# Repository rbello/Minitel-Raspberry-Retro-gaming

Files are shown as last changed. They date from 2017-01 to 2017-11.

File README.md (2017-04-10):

# Retro gaming video game console + Old French Minitel (DIY)

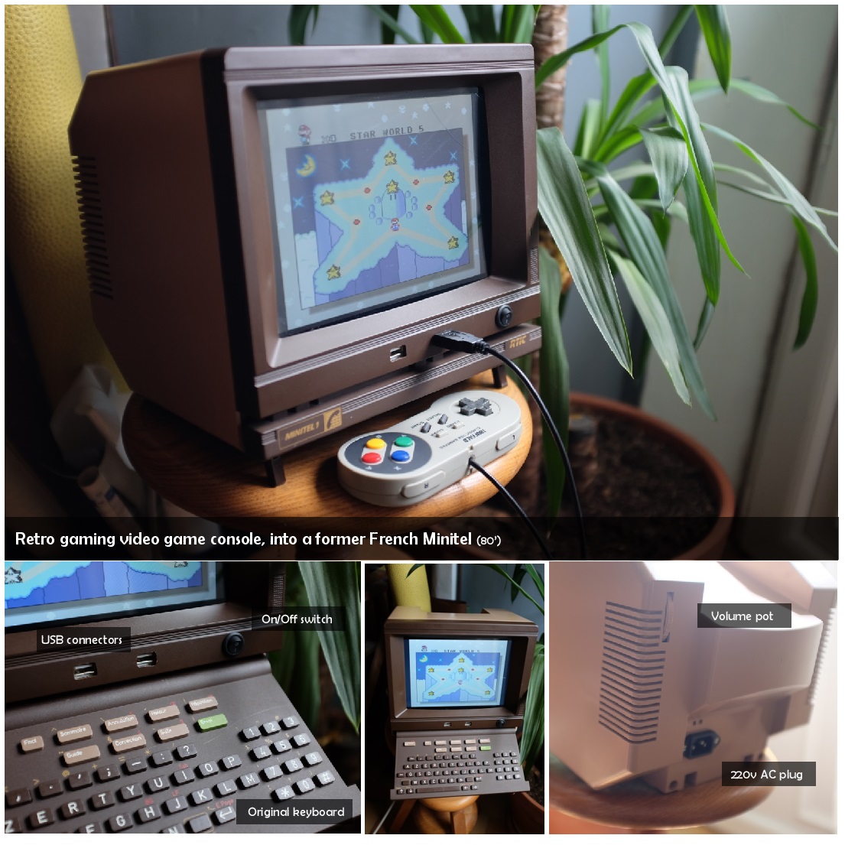
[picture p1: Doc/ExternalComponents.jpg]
External components


### A SuperSwag Project

The Minitel was a Videotex online service accessible through telephone lines, and is considered one of the world's most successful pre-World Wide Web online services. The service was rolled out in France in 1982 by the *Postes, Télégraphes et Téléphones* compagny. From its early days, users could make online purchases, make train reservations, check stock prices, search the telephone directory, have a mail box, and chat in a similar way to that now made possible by the Internet. Then, this service was retired on 30 June 2012.

Minitel used terminals consisting of a text-based screen, keyboard and modem. Simple graphics could be displayed using a set of predefined graphical characters. It used a half-duplex asymmetric data transmission via its modem. It downlinked at 1200 bit/s and uplinked at 75 bit/s. This allowed fast downloads, for the time.

I decided to reuse an old minitel in order to make a retro gaming console, because the case is cute and contains an embedded screen. To make the system work, I used a Raspberry Pi as a computer, an Arduino Nano to control power and peripherals, a 10'' LCD and a stereo speaker. I managed to reuse the original keyboard (with some DIY) but I also added two front USB ports to connect more modern peripherals, such as gamepads.

Here's how it works:

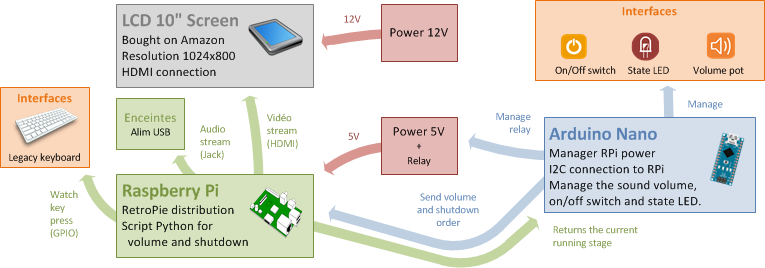
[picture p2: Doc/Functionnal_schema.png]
Functionnal schema


Inside, I had to make a plastic support thanks to a 3D printer to contain all the electronic components. The Arduino Nano manages the life cycle of the system. It communicates with the Raspberry using the I2C connection to send him the sound volume value (which can be changed with the minitel's original pot) and the order of shutdown. The Raspberry contains a special retro gaming linux distribution that ships all the emulators from consoles prior to the PlayStation. The display is ensured by an LCD screen specially bought for the occasion, which I had to cut out to adapt it to the original box.

Here's what it looks like inside the box:

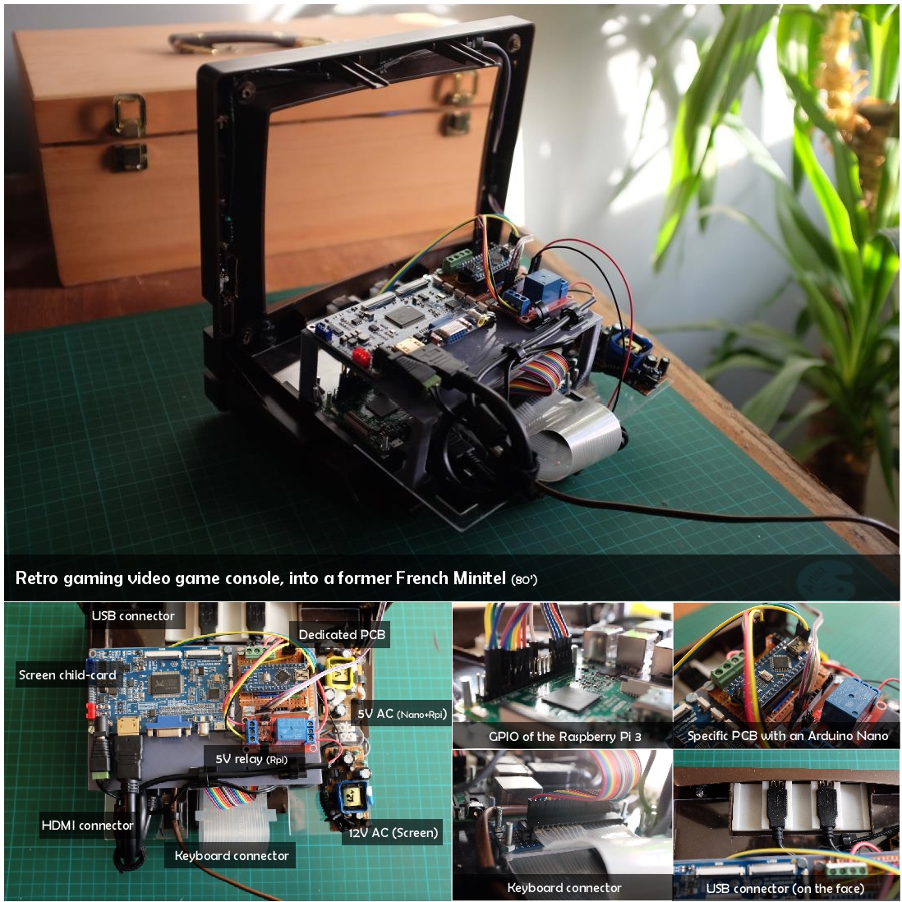
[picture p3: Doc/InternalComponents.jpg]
Internal components


### Conception

#### Power management / Electronic design
Naturally, raspberry is not able to handle an on/off button that allows the power supply to be turned off properly once the embedded linux has shutdown. To do this, I have added an arduino that controls the power supply and manages the system life cycle.

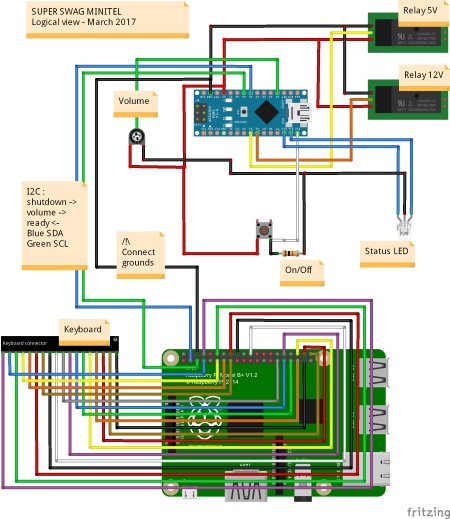
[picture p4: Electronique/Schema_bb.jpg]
Electronic schema


- [Arduino Sketch : INO file](https://github.com/rbello/Minitel-Raspberry-Retro-gaming/blob/master/SuperSwag3615.ino)
- [Python script : I2C connection polling](https://github.com/rbello/Minitel-Raspberry-Retro-gaming/blob/master/Scripts%20Raspberry/polling.py)
- [Bash script : startup process](https://github.com/rbello/Minitel-Raspberry-Retro-gaming/blob/master/Scripts%20Raspberry/startup.sh)

#### Keyboard
The original minitel keyboard is connected directly to the raspberry pi. It works perfectly with the following script:
- [Python script : Keyboard polling](https://github.com/rbello/Minitel-Raspberry-Retro-gaming/blob/master/Scripts%20Raspberry/keyboard.py)

#### 3D printed components
To integrate all the components in the case and offer USB interfaces on the front, I printed several plastic components using a 3D printer. Models are available in the Casing directory.
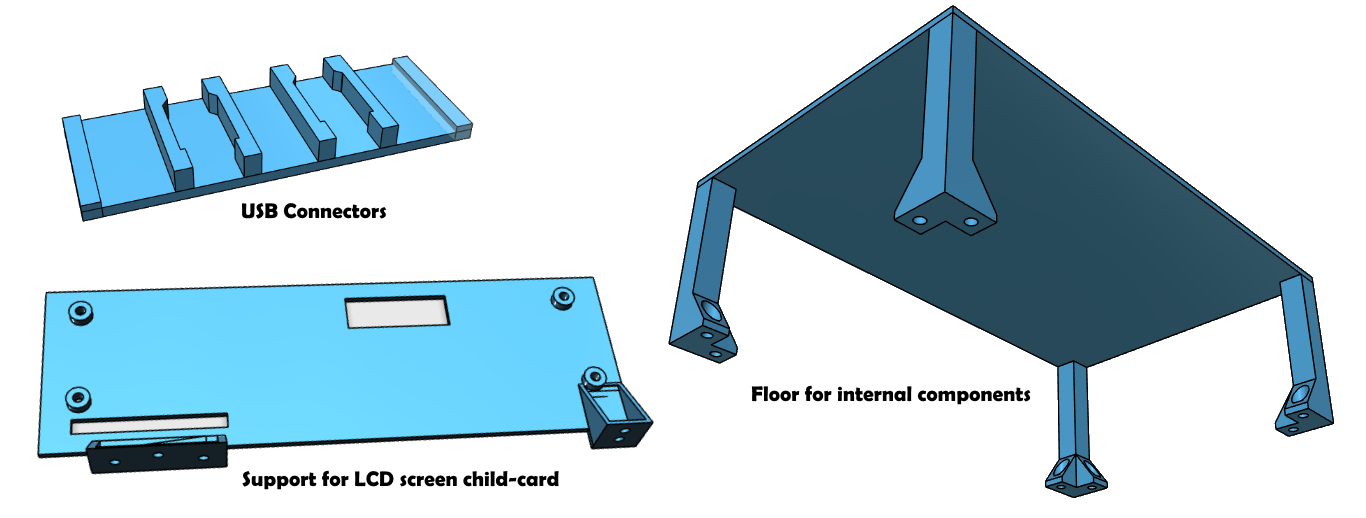
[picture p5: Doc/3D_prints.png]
3D prints


#### Materials

- The Raspberry Pi 3 (Model B) as main engine
- Arduino Nano (from SODIAL)
- [10.1 inch LCD touch screen](https://www.amazon.fr/gp/product/B01E8O5B20/ref=oh_aui_detailpage_o00_s00?ie=UTF8&psc=1)
- A simple USB audio speaker with Jack connector

#### Software

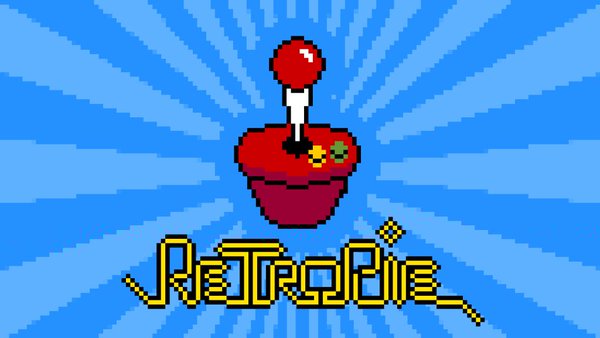
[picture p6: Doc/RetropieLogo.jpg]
RetropieLogo


On the raspberry pi:
- Installed Operating System : [RetroPie](https://retropie.org.uk/)
- Plus some linux packages: i2c-tools and python-smbus, alsa-utils (for sounds), python-uinput (for keyboard)
- I also replaced the [/boot/config.txt](https://github.com/rbello/Minitel-Raspberry-Retro-gaming/blob/master/Scripts%20Raspberry/config.txt) to adapt screen resolution
- See [setup document](https://github.com/rbello/Minitel-Raspberry-Retro-gaming/blob/master/Scripts%20Raspberry/setup.txt) for more details

I also used:
- Scraper : [Universal XML Scraper](https://github.com/Universal-Rom-Tools/Universal-XML-Scraper/releases)

#### Automatic Synch

The console automatically synchronizes game saves backups with an HTTP server. A raspberry-side python script and a server-side PHP script ensure the synchronization of files periodically, thanks to a CRON task.

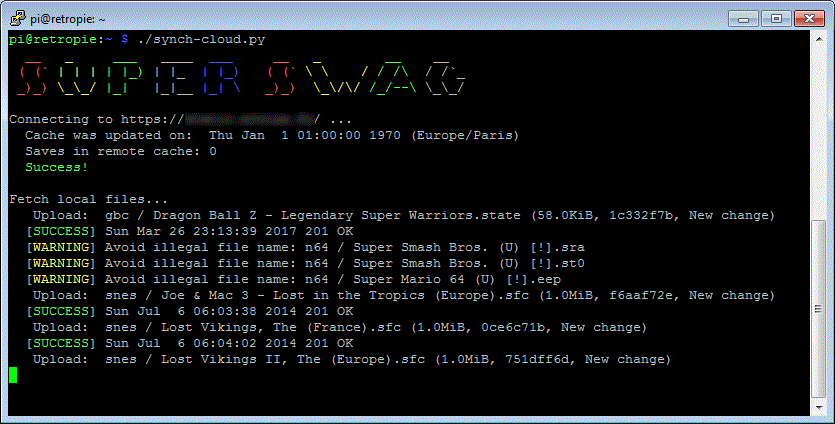
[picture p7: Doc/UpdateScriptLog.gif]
SynchScript


[Python](https://github.com/rbello/Minitel-Raspberry-Retro-gaming/blob/master/Scripts%20Raspberry/synch-cloud.py) and [PHP](https://github.com/rbello/Minitel-Raspberry-Retro-gaming/blob/master/Synchro/index.php) scripts uses an OTP authentication using algorithms specified in RFC 6238 and RFC 4226 (also used by Google Authenticator).

*This repository contains all the files allowing the creation of a similar console. This content is copyright free.*

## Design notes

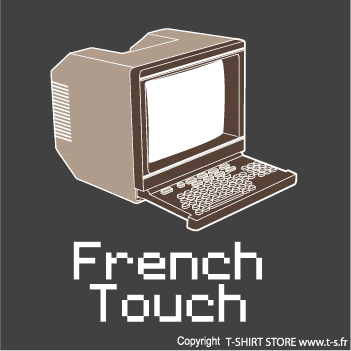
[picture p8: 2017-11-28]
Doc/Recherche1.gif

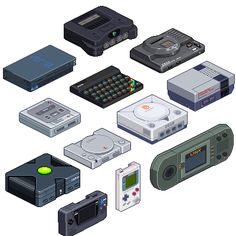
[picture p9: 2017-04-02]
Doc/ConsolesRetro.jpg

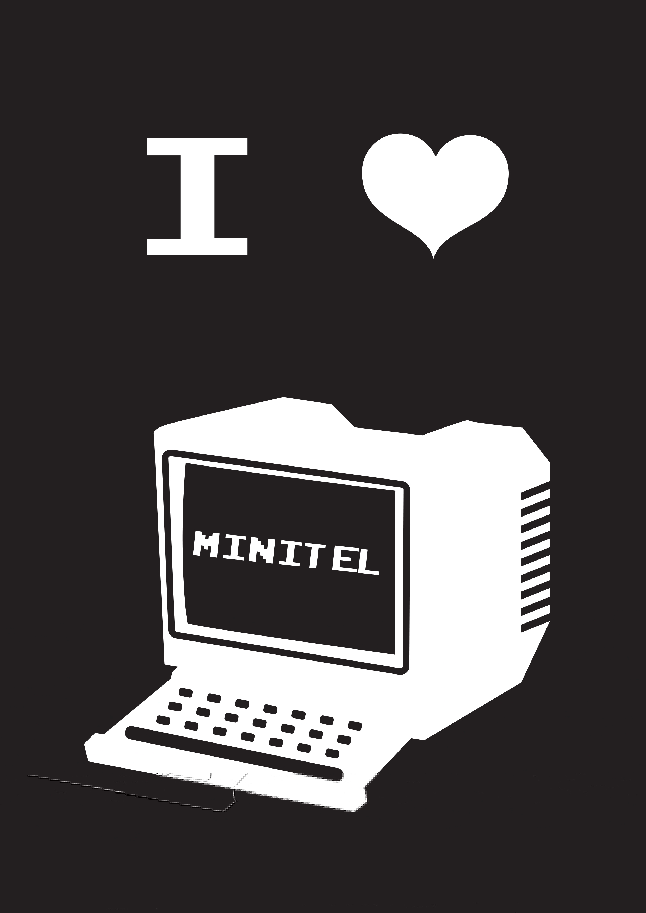
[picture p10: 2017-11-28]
Doc/Recherche2.jpg

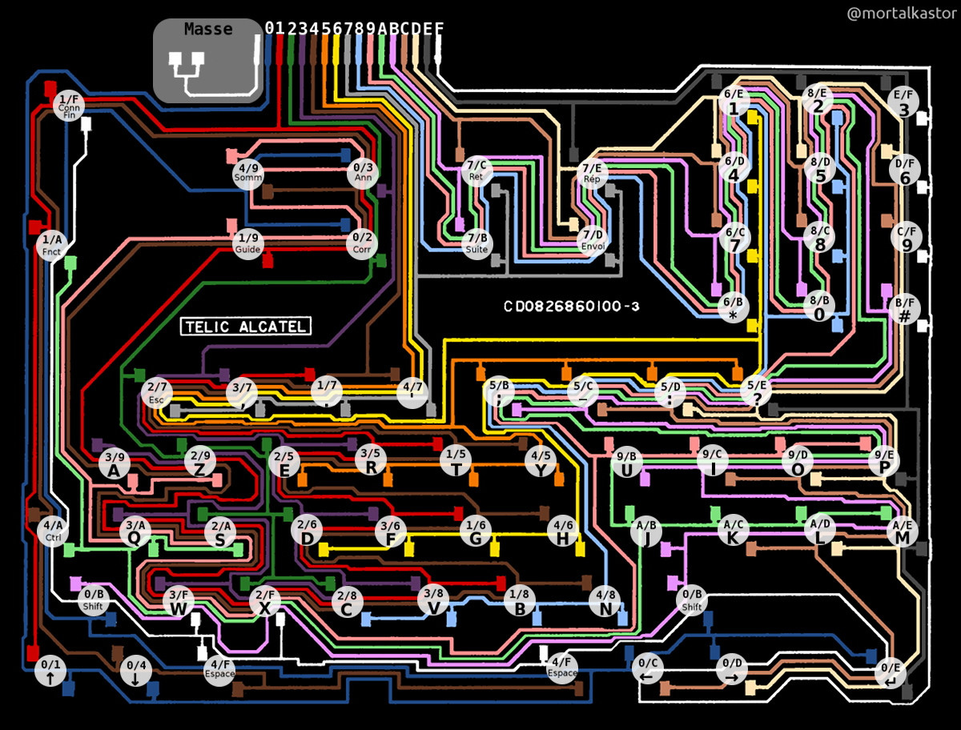
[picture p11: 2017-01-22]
Electronique/DWOEDv0.jpg

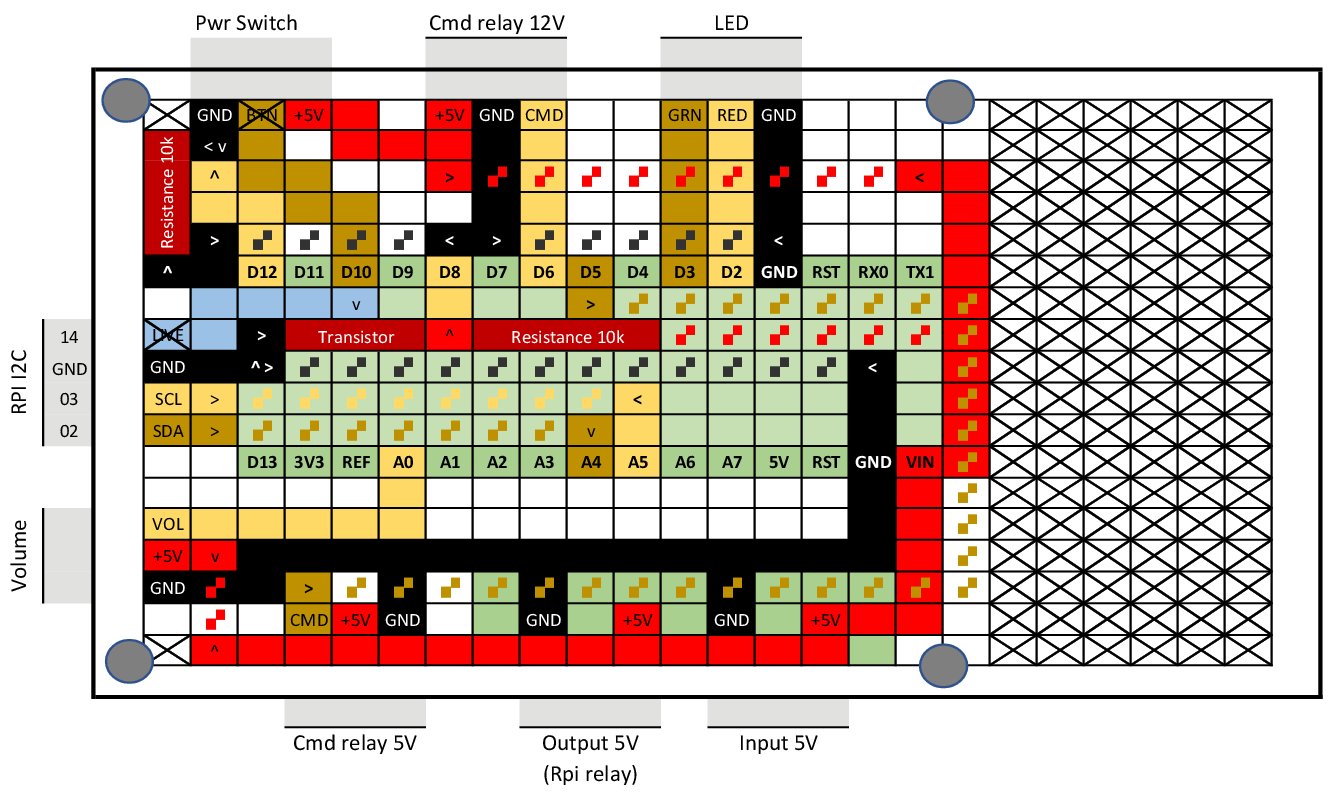
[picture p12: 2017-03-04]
Electronique/Routage.png

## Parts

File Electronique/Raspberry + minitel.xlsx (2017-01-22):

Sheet: Liste
Lien | Utilisation | Projet | Prix Unitaire | Quantité | Prix Total
5 m Rallonge Connecteur de cube / Embrayage de cube (https://www.amazon.fr/gp/product/B00PG8L1ZO/ref=ox_sc_act_title_1?ie=UTF8&psc=1&smid=A1HOTMS12DU4AQ) | Câble DIN | DIN | 1.99 € | 1 | 1.99 €
SODIAL(R) Pour PL2303HX USB Adapter Module RS232 TTL Auto Convertisseur pour Arduino W / Cables (https://www.amazon.fr/gp/product/B00K67X3KG/ref=ox_sc_act_title_2?ie=UTF8&psc=1&smid=A3I826466U8R8A) | Module conversion vidéo DIN | DIN | 1.70 € | 1 | 1.70 €
 |  |  |  |  | 0.00 €
Ecran haute résolution 1024 XÁ 600 10" tactile capacitif LCD HDMI pour Raspberry Pi 2 Model B / Raspberry Pi B / B + / A + (https://www.amazon.fr/gp/product/B01E8O5B20/ref=ox_sc_act_title_3?ie=UTF8&psc=1&smid=A2OQ98EEMD0IEL) | Ecran LCD 10" (22,2x12,5) | LCD | 98.90 € | 1 | 98.90 €
 |  |  |  |  | 0.00 €
Rallonge USB 2.0 - A mâle / A femelle - 50cm (Lindy 31849) (https://www.amazon.fr/gp/product/B004CDSC9M/ref=ox_sc_act_title_4?ie=UTF8&psc=1&smid=A1X6FK5RDHNB96) | Rallonge USB 50cm | Manettes | 3.70 € | 2 | 7.40 €
StarTech.com USBEXTAA6IN Câble d'Extension Mâle/Femelle USB 2.0 de 15.2 cm Prolongateur USB rallonge (https://www.amazon.fr/gp/product/B000E5CYW8/ref=ox_sc_act_title_5?ie=UTF8&psc=1&smid=A1X6FK5RDHNB96) | Rallonge USB 15cm | Manettes | 1.99 € | 1 | 1.99 €
 |  |  |  |  | 0.00 €
Logitech - 980-000513 - Stereo Speakers Z120 - Haut-parleurs 2.0 1.2 Watts - Blanc (https://www.amazon.fr/gp/product/B00544XKK4/ref=ox_sc_act_title_1?ie=UTF8&psc=1&smid=A1X6FK5RDHNB96) | Enceintes USB/Jack | Enceintes | 13.77 € | 1 | 13.77 €
 |  |  |  |  | 0.00 €
 |  |  |  |  | 0.00 €
 |  |  |  |  | 125.75 €
Minitel + DIN | http://blog.uggy.org/?post/2015/02/22/Minitel-et-Raspberry |  |  |  | http://pila.fr/wordpress/?p=361
Minitel + clavier | https://wiki.labomedia.org/index.php/Renaissance_d%27un_Minitel_avec_une_Raspberry_Pi
Regarder les commentaires !! | https://www.youtube.com/watch?v=eKnKXKM9_CM&feature=player_detailpage#t=125

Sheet: Dimensions
Largeur : | 22.20 | 492.84 | 25.47724475 | 10.03041673
Hauteur : | 12.50 | 156.25 | cm | pouces
Largeur : | 18.10 | 327.61 | 22.43150686 | 8.831306682
Hauteur : | 13.25 | 175.5625 | cm | pouces

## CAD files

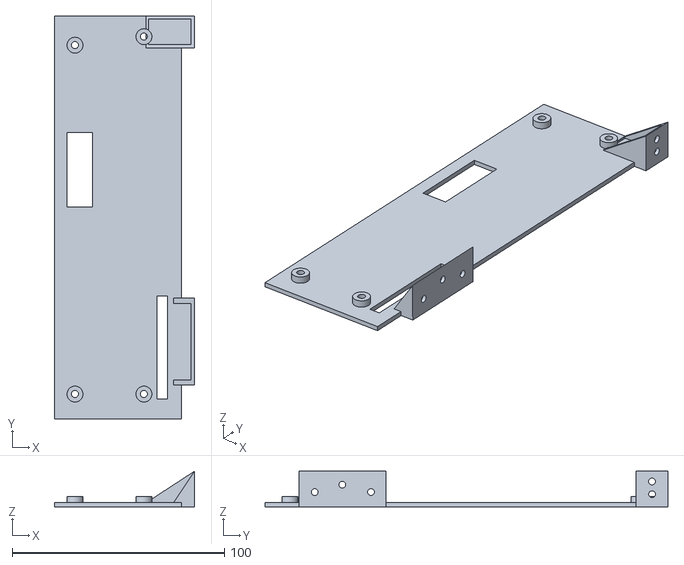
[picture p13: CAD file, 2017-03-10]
Casing/Support de l'écran 4.stl
66.2 x 190.0 x 16.9

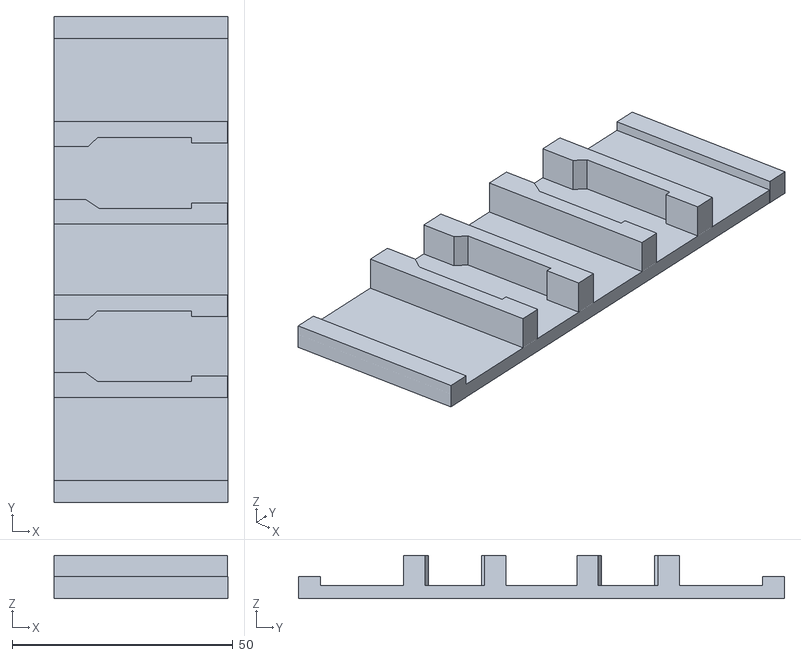
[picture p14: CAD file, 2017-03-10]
Casing/Support des ports USB.stl
39.3 x 110.0 x 9.80

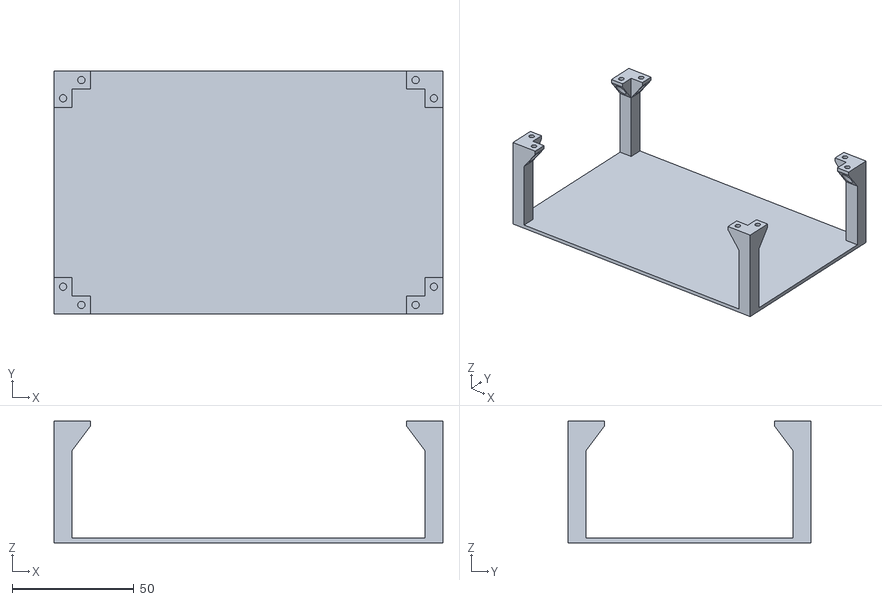
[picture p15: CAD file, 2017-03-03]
Casing/Plateau etage.stl
160.0 x 100.0 x 50.0

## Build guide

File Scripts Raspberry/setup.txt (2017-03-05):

#!/bin/bash

### Tester la connexion i2c entre raspberry et arduino
i2cdetect -y 1
#i2cdetect -y 0

# Script de lancement
sudo chmod +x /home/pi/startup.sh
echo crontab -l | { echo "@reboot /home/pi/startup.sh"; } | crontab -

### Setup de la lib smbus néccessaire pour le polling
sudo apt-get install i2c-tools
sudo apt-get install python-smbus

### Configuration de raspi-config
# Ajouter "i2c-dev" au fichier /etc/modules
# Activer le port I2C dans les options avancées de raspi-config

# Ajouter dans /boot/config.txt  (pour la Rpi 3, si ce dtparam n'existe pas)
# dtparam=i2c_arm=on

### Setup de la lib pour le son
sudo apt-get install alsa-utils
sudo modprobe snd_bcm2835
# Force la sortie jack
sudo amixer cset numid=1

# En fin
sudo reboot

# Configuration de l'écran
# A ajouter à /boot/config.txt
max_usb_current=1
hdmi_group=2
hdmi_mode=1
hdmi_mode=87
hdmi_cvt 1024 600 60 6 0 0 0

### Clavier
###
# Desactiver la fonction SERIAL dans les options avancées de raspi-config (permet d'utiliser la GPIO 15)
wget https://bootstrap.pypa.io/get-pip.py
python get-pip.py
pip install python-uinput
# Ajouter "uinput" à /etc/modules

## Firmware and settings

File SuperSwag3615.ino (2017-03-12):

//    _________                          _________                        
//   /   _____/__ ________   ___________/   _____/_  _  _______     ____  
//   \_____  \|  |  \____ \_/ __ \_  __ \_____  \\ \/ \/ /\__  \   / ___\ 
//   /        \  |  /  |_> >  ___/|  | \/        \\     /  / __ \_/ /_/  >
//  /_______  /____/|   __/ \___  >__| /_______  / \/\_/  (____  /\___  / 
//          \/      |__|        \/             \/              \//_____/  
//
// This file is a part of the SuperSwag projet.
// Copyleft 2017 - evolya.fr

#include <Wire.h>

// -- Configuration des pins

#define PIN_LED_R 2       // Pin LED couleur ROUGE
#define PIN_LED_Y 3       // Pin LED couleur VERT
#define PIN_PWR_RPI 5     // Pin allumage alimentation Raspberry Pi (5V)
#define PIN_PWR_SCREEN 6  // Pin allumage alimentation Ecran (12V)
#define PIN_SWITCH 12     // Pin du switch On/Off
#define PIN_POT A0        // Pin du potentiomètre du volume sonore

// -- Configuration des délais (en ms)

#define TTL_STARTING 30000
#define TTL_SHUTDOWN 30000
#define LED_BLINK_DELAY 500
#define SHUTDOWN_SAFETY_DELAY 10000
#define RPI_ALIVE_TTL 2000

// -- Configurations avancées

#define SERIAL_BAUDRATE 9600    // Taux de transmission de l'arduino pour la liaison série
#define SLAVE_ADDRESS 0x04      // Adresse I2C de l'arduino
#define SHUTDOWN_ON_ERROR false // Couper l'alimentation de la Rpi si le démarrage échoue

// -- Etats possibles du système

#define STATE_OFF 0       // Le système est arrêté
#define STATE_STARTING 1  // Le système est en cours de démarrage
#define STATE_STARTED 2   // Le système est démarré et en fonctionnement
#define STATE_SHUTDOWN 3  // Le système est en cours d'arrêt

// Enregistre l'état actuel du système
int generalState = STATE_OFF;

// Utilisés pour gérer l'état de la LED clignotante
bool ledState = true;
long ledTimer = 0;

// Enregistre le moment où à commencé le lancement ou l'arrêt du système
long startStopTime = 0;

// Volume (de 0 à 100)
int volume = 0;

// Etat du bouton On/Off : ouvert ou fermé
bool switchState = false;

// Timestamp du moment où vérifier l'état de la RPI (par gpio)
long rpiCheckTime = 1;

// Valeur du pin PIN_RUNNING (temporisé pour éviter le changement trop rapide d'état lors du lancement de la rpi)
int rpiPinValue = 0;

// Conserve l'état de lancement du script python sur le raspberry
bool rpiState = false;

// Tempon d'écriture I2C vers le raspberry
volatile byte e_keys;

// Timestamp de la dernière requête de la RPI
long rpiLastRequest = 0;

// Indique si la raspberry est connectée en I2C
// Si cette variable est >2 on peut considérer que la RPi est connectée
int rpiConnected = 0;

// Quand le maitre (raspberry) demande quelque chose à l'esclave (arduino)
void i2c_requests()
{
  // On horodate la dernière requête du master
  rpiLastRequest = millis();
  // Si la RPi est déconnectée actuellement
  if (rpiConnected < 3) {
    // On incrémente le compteur d'activité
    rpiConnected++;
    // Si désormais le nombre de requête est suffisant pour considérer que la connexion est établie avec fiabilité
    if (rpiConnected > 2) {
      Serial.println("Raspberry was connected!");
      digitalWrite(PIN_LED_R, LOW);
      digitalWrite(PIN_LED_Y, HIGH);
      // Si on est en état de démarrage, cela signifie que la Rpi est prête
      if (generalState == STATE_STARTING) {
        generalState = STATE_STARTED;
        Serial.println("New state: STARTED");
      }
    }
    // Sinon on attend encore...
    else return;
  }
  // Aucun message à envoyer
  if (e_keys == 0) return;
  // On a un message à envoyer
  Wire.write(e_keys);
  Serial.print("I2C sent: ");
  Serial.println((int)e_keys);
  e_keys = 0;
}

void i2c_sendData(byte value)
{
  // Rien ne peut empêcher le signal de shutdown
  if (e_keys != 201)
    e_keys = value;
}

void setup()
{
  
  Serial.begin(SERIAL_BAUDRATE);
  Serial.println("Init...");

  pinMode(PIN_SWITCH, INPUT);
  digitalWrite(PIN_SWITCH, HIGH);
  
  pinMode(PIN_LED_R, OUTPUT);
  pinMode(PIN_LED_Y, OUTPUT);
  digitalWrite(PIN_LED_R, LOW);
  digitalWrite(PIN_LED_Y, LOW);
  
  pinMode(PIN_PWR_RPI, OUTPUT);
  pinMode(PIN_PWR_SCREEN, OUTPUT);
  setPowerEnabled(false);

  pinMode(PIN_POT, INPUT);

  // Initialisation I2C
  Wire.begin(SLAVE_ADDRESS);
  delay(50);
  Wire.onRequest(i2c_requests);

  Serial.println("New state: OFF");
  Serial.println("Ready!");
}

void startblink(int pinColor)
{
  digitalWrite(PIN_LED_R, pinColor == PIN_LED_R ? HIGH : LOW);
  digitalWrite(PIN_LED_Y, pinColor == PIN_LED_Y ? HIGH : LOW);
  ledState = true;
  ledTimer = startStopTime = millis();
}

void ledblink(int colorPin)
{
  ledState = !ledState;
  digitalWrite(colorPin, ledState ? HIGH : LOW);
  ledTimer = millis();
}

void sendShutdownSignal()
{
  i2c_sendData(201);
}

void setPowerEnabled(bool enabled)
{
  Serial.print("Set power: ");
  Serial.println(enabled ? "ON" : "OFF");
  digitalWrite(PIN_PWR_RPI, enabled ? HIGH : LOW);
  digitalWrite(PIN_PWR_SCREEN, enabled ? HIGH : LOW);
}

void setStateStarting()
{
  // Changement d'état
  startStopTime = millis();
  generalState = STATE_STARTING;
  Serial.println("New state: STARTING");
  // On commence un clignotement vert
  startblink(PIN_LED_Y);
  // Allumage de l'alimentation des autres composants
  setPowerEnabled(true);
  // On met un petit temps avant de continuer le programme, pour éviter une remontée
  // trop rapide de l'I2C
  delay(100);
}

void setStateShutdown() {
  // Changement d'état
  generalState = STATE_SHUTDOWN;
  Serial.println("New state: SHUTDOWN");
  // On envoie l'interruption au Rpi
  sendShutdownSignal();
  // On commence un clignotement rouge
  startblink(PIN_LED_R);
}

void handleStarting()
{
  // Détection de l'expiration du délais maximum de lancement de la Rpi
  if (millis() - startStopTime > TTL_STARTING) {
    Serial.println("Error: maximum time to start is reached !");
    generalState = STATE_OFF;
    Serial.println("New state: OFF (with failure)");
    digitalWrite(PIN_LED_R, HIGH);
    digitalWrite(PIN_LED_Y, LOW);
    // On coupe l'alimentation
    if (SHUTDOWN_ON_ERROR) setPowerEnabled(false);
    return;
  }
  // Sinon : clignotement de LED lors du démarrage
  if (millis() - ledTimer > LED_BLINK_DELAY) {
    ledblink(PIN_LED_Y);
  }
}

void handleShutdown()
{
  // Détection de l'expiration du délais maximum d'arrêt de la Rpi
  if (millis() - startStopTime > TTL_SHUTDOWN) {
    Serial.println("Error: maximum time to shutdown is reached !");
    generalState = STATE_OFF;
    Serial.println("New state: OFF (with failure)");
    digitalWrite(PIN_LED_R, LOW);
    digitalWrite(PIN_LED_Y, LOW);
    // On coupe l'alimentation
    setPowerEnabled(false);
    return;
  }
  // Sinon : clignotement de LED lors de l'arrêt
  if (millis() - ledTimer > LED_BLINK_DELAY) {
    ledblink(PIN_LED_R);
  }
}

void setStarted(bool onOff) {
  Serial.print("Consigne bouton : ");
  Serial.println(onOff ? "ON" : "OFF");
  // Et on modifie l'état
  if (onOff && generalState == STATE_OFF)       setStateStarting();
  if (!onOff && generalState == STATE_STARTED)  setStateShutdown();
}

void loop()
{

  ////// 
  //////  GESTION DU BOUTON ON/OFF
  //////
  int btn = digitalRead(PIN_SWITCH);
  // Changement d'état du bouton ON/OFF
  if (btn != switchState) {
    // On ajoute ici une petite vérification de l'état après 10ms, afin d'éviter des changements d'états trop rapides (bruit)
    delay(10);
    btn = digitalRead(PIN_SWITCH);
    if (btn == switchState) {
      // Si l'état est revenu à l'état initial, on ne fait rien
    }
    else if (btn == 1 && generalState == STATE_OFF) {
      setStarted(true);
    }
    else if (btn == 0 && generalState == STATE_STARTED) {
      setStarted(false);
    }
    switchState = btn;
  }

  // Gestion des changements d'états
  if (generalState == STATE_STARTING) handleStarting();
  if (generalState == STATE_SHUTDOWN) handleShutdown();

  ////// 
  //////  GESTION DE LA MOLETTE DU VOLUME
  //////
  if (generalState == STATE_STARTED) {
    int snd = analogRead(PIN_POT);
    int delta = abs(volume - snd);
    if (delta > 25) {
      int cl = (int)((float)snd / 1024.0 * 99.0) + 1;
      Serial.print("Volume : ");
      Serial.print(cl);
      Serial.println("%");
      volume = snd;
      i2c_sendData(cl);
    }
  }

  ////// 
  //////  GESTION DES ENTREES SERIE
  //////
  if (Serial.available()) {
    String data = Serial.readString();
    if (data == "help") {
      Serial.println("Commands :");
      Serial.println("  on | off    Change current consigne");
      Serial.println("  test-i2c    Sent 111 to the raspberry pi");
      Serial.println("  shutdown    Shutdown the raspberry pi");
      Serial.println("  reboot      Reboot the raspberry pi");
    }
    else if (data == "on") {
      setStarted(true);
    }
    else if (data == "off") {
      setStarted(false);
    }
    else if (data == "test-i2c") {
      i2c_sendData(111);
    }
    else if (data == "shutdown") {
      sendShutdownSignal();
    }
    else if (data == "reboot") {
      i2c_sendData(202);
    }
    else {
      Serial.println("Invalid commande. Type help to list available commands.");
    }
  }

  if (rpiConnected > 2 && millis() - rpiLastRequest >= RPI_ALIVE_TTL) {
    Serial.println("Raspberry was disconnected...");
    rpiConnected = 0;
    digitalWrite(PIN_LED_R, HIGH);
    digitalWrite(PIN_LED_Y, LOW);
    if (generalState == STATE_SHUTDOWN) {
      // On attend encore un petit peu par sécurité
      delay(SHUTDOWN_SAFETY_DELAY);
      generalState = STATE_OFF;
      Serial.println("New state: OFF");
      digitalWrite(PIN_LED_R, LOW);
      digitalWrite(PIN_LED_Y, LOW);
      // On coupe l'alimentation
      setPowerEnabled(false);
    }
  }

}

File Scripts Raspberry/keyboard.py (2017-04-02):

#!/usr/bin/env python

#    _________                          _________                        
#   /   _____/__ ________   ___________/   _____/_  _  _______     ____  
#   \_____  \|  |  \____ \_/ __ \_  __ \_____  \\ \/ \/ /\__  \   / ___\ 
#   /        \  |  /  |_> >  ___/|  | \/        \\     /  / __ \_/ /_/  >
#  /_______  /____/|   __/ \___  >__| /_______  / \/\_/  (____  /\___  / 
#          \/      |__|        \/             \/              \//_____/  
#
# This file is a part of the SuperSwag projet.
# Copyleft 2017 - evolya.fr
#
#@see https://wiki.labomedia.org/index.php/Renaissance_d%27un_Minitel_avec_une_Raspberry_Pi
#@see http://crumpspot.blogspot.fr/2013/05/using-3x4-matrix-keypad-with-raspberry.html

import RPi.GPIO as GPIO
import uinput
import os
import time

class keypad():

	# Minitel 1 RTIC keyboard (text)
	KEYNAME = [
		["Caps L",     "W",       "B",           "N",    "Caps R", "V",     "C",     "X",     "[0x8]"],
		["Q",          "D",       "G",           "J",    "L",      "7",     "8",     "9",     "[1x8]"],
		["Ctrl",       "S",       "F",           "H",    "K",      "M",     "P",     "O",     "[2x8]"],
		["A",          "Z",       "E",           "R",    "T",      "Y",     "U",     "I",     "[3x8]"],
		["Esc",        ",",       ".",           "'",    ";",      "-",     ":",     "?",     "[4x8]"],
		["Connection", "Guide",   "Correction", "Next",  "Send",   "4",     "5",     "6",     "[5x8]"],
		["Fnct",       "Summary", "Cancel",     "Back",  "Repeat", "1",     "2",     "3",     "[6x8]"],
		["Up",         "Down",    "Left",       "Right", "Enter",  "*",     "0",     "#",     "Space"],
		["[8x0]",      "[8x1]",   "[8x2]",      "[8x3]", "[8x4]",  "[8x5]", "[8x6]", "[8x7]", "[8x8]"]
	]

	ALLOW_COMBINE = ["Caps L", "Caps R", "Fnct", "Ctrl"]
	
	# Minitel 1 RTIC keyboard (uinput)
	KEYPAD = [
		[uinput.KEY_LEFTSHIFT,  uinput.KEY_W,      uinput.KEY_B,          uinput.KEY_N,           uinput.KEY_RIGHTSHIFT,  uinput.KEY_V,           uinput.KEY_C,      uinput.KEY_X,         None],
		[uinput.KEY_Q,          uinput.KEY_D,      uinput.KEY_G,          uinput.KEY_J,           uinput.KEY_L,           uinput.KEY_7,           uinput.KEY_8,      uinput.KEY_9,         None],
		[uinput.KEY_LEFTCTRL,   uinput.KEY_S,      uinput.KEY_F,          uinput.KEY_H,           uinput.KEY_K,           uinput.KEY_M,           uinput.KEY_P,      uinput.KEY_O,         None],
		[uinput.KEY_A,          uinput.KEY_Z,      uinput.KEY_E,          uinput.KEY_R,           uinput.KEY_T,           uinput.KEY_Y,           uinput.KEY_U,      uinput.KEY_I,         None],
		[uinput.KEY_ESC,        uinput.KEY_COMMA,  uinput.KEY_DOT,        uinput.KEY_APOSTROPHE,  uinput.KEY_SEMICOLON,   uinput.KEY_MINUS,       uinput.KEY_TAB,    uinput.KEY_QUESTION,  None], # Todo deux-points (tab)
		[uinput.KEY_CONNECT,    uinput.KEY_HELP,   uinput.KEY_BACKSPACE,  uinput.KEY_NEXT,        uinput.KEY_SEND,        uinput.KEY_4,           uinput.KEY_5,      uinput.KEY_6,         None],
		[uinput.KEY_FN,         uinput.KEY_LIST,   uinput.KEY_CANCEL,     uinput.KEY_BACK,        uinput.KEY_REDO,        uinput.KEY_1,           uinput.KEY_2,      uinput.KEY_3,         None],
		[uinput.KEY_UP,         uinput.KEY_DOWN,   uinput.KEY_LEFT,       uinput.KEY_RIGHT,       uinput.KEY_ENTER,       uinput.KEY_KPASTERISK,  uinput.KEY_0,      uinput.KEY_TAB,       uinput.KEY_SPACE], # Todo diese (tab)
		[None,                  None,              None,                  None,                   None,                   None,                   None,              None,                 None]
	]

	# My own attached pins
	ROW         = [26, 21, 20, 19, 16, 13,  6, 12, 5]
	COLUMN      = [25, 24, 22, 23, 27, 17, 18, 4, 14]

	# Virtual keyboard device for uinput
	DEVICE      = None

	# Extra keys
	extraKeys = []
	
	# Observers
	observers = []

	def start(self):
		# Configure GPIO designation model
		GPIO.setmode(GPIO.BCM)
		# Map input keys
		map = []
		for row in self.KEYPAD:
			for key in row:
				if key is not None:
					map.append(key)
		for key in self.extraKeys:
			map.append(key)
		self.DEVICE = uinput.Device(map)

	def getKey(self):
		# Set all columns as output low
		for j in range(len(self.COLUMN)):
			GPIO.setup(self.COLUMN[j], GPIO.OUT)
			GPIO.output(self.COLUMN[j], GPIO.LOW)
		
		# Set all rows as input
		for i in range(len(self.ROW)):
			GPIO.setup(self.ROW[i], GPIO.IN, pull_up_down=GPIO.PUD_UP)
		
		# Scan rows for pushed key/button
		rowVal = -1
		for i in range(len(self.ROW)):
			tmpRead = GPIO.input(self.ROW[i])
			if tmpRead == 0:
				rowVal = i
				 
		# if rowVal is not set then no button was pressed and we can exit
		if rowVal < 0 or rowVal >= len(self.ROW):
			self.exit()
			return
		
		# Convert columns to input
		for j in range(len(self.COLUMN)):
			GPIO.setup(self.COLUMN[j], GPIO.IN, pull_up_down=GPIO.PUD_DOWN)
		
		# Switch the i-th row found from scan to output
		GPIO.setup(self.ROW[rowVal], GPIO.OUT)
		GPIO.output(self.ROW[rowVal], GPIO.HIGH)
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

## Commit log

2017-01-08 Mise en conf
    [Routage.xlsx, Schema.fzz]
2017-01-22 Keyboard documentation
    [Raspberry + minitel.xlsx, Schema.fzz]
2017-03-03 Casing cleanup
    [Pillier.stl, Plateau etage.stl, Socle USB.stl]
2017-03-03 Electronic shema need to be updated
    [Schema.fzz]
2017-03-03 Update rpi scripts and arduino sketch
2017-03-04 MAJ routage
    [Routage.xlsx]
2017-03-04 Some fixes on arduino sketch
    [SuperSwag3615.ino]
2017-03-04 Doc + cleanup + correct keyboard mapping
    [keyboard.py, polling.py]
2017-03-05 Update screen holder
    [Support carte fille ecran 2.stl]
2017-03-05 Update documentation
    [Schema.fzz]
2017-03-05 Cleanup arduino sketch
2017-03-10 Casing parts cleanup
    [Support carte fille ecran 2.stl, Support de l'écran 4.stl, Support des ports USB.stl]
2017-03-10 Improve power management stability
    [SuperSwag3615.ino]
2017-03-12 Improve behavior of LED
2017-03-12 Keyboard works ! Need to fix keys and combo
    [keyboard.py]
2017-03-31 Add /root/boot.txt
    Scale screen to minitel's width
    [config.txt]
2017-04-01 Add observer to fix minitel keyboard
    [keyboard.py]
2017-04-01 Disable emit click (bug)
    [keyboard.py, keydebug.py]
2017-04-01 Revert "Disable emit click (bug)"
    This reverts commit 0cfeaa580a9b72711fcdd13901d9a0394e3c1e5b.
    [keyboard.py, keydebug.py]
2017-11-28 Add graphics for box printing
